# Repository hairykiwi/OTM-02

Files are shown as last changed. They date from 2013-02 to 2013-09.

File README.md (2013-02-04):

Open source Time Machine #2 - OTM-02
======

###About
OTM-02 is an open source watch module designed using [KiCad](http://www.kicad-pcb.org).
The project has a strong focus on using readily available off-the-shelf recent or latest technology, from global suppliers.

For the last few years I have eagerly awaited this period in time when really cool ultra-low power technology is readily available to the masses - so it's only right that a huge thanks goes out to Sharp Microelectronics for developing Memory LCD technology  - and an equally huge thanks goes to Energy Micro (EM) for not only supplying their ultra low power range of MCUs, but for having a level of customer support in place that even a relative novice like me feels they might just about be able to make something quite exciting. Within the Energy Micro team I would like to pay special thanks to Anders, Filip and Adam, without whose heavy-lifting work they've done with [code for Memory LCD](http://cdn.energymicro.com/dl/an/zip/an0048_efm32_energy_friendly_display.zip) technology, my current Memory LCD code would not be as efficiently integrated with EM's MCUs.

Right, enough waffle, you're here about a watch...

###Development
2013-02-02:
- [A functional development prototype does exists](http://dl.dropbox.com/u/18290329/hosted/OTM/OTM-01%20and%203D%20printed%20case%20concept_25pc.jpg). It uses a first generation Memory LCD model.
- No prototype has yet been manufactured - one is expected to be ready for showing by the end of Feb 2013.

A [discussion thread](http://forum.energymicro.com/topic/582-otm-02-open-source-time-machine-2/) has been posted at Energy Micro's [Lizard Lounge](http://forum.energymicro.com/) forum, where any questions, comments, critique, and suggestions for improvements are all welcome and appreciated.

###Objectives
- Create a watch module that enables the end user to have complete control of its functionality and user interface,
- Discover the benefits - and any detractions - of (potentially selling) a product developed from the outset in true open source hardware style,
- Self-education,
- Discover how much technology can be crammed into a wristwatch designed - and possibly manufactured - 'on the living room table',
- Design a module that with only a little extra effort, could form the basis of other devices, e.g. cycle computer, dive computer, data logger, etc.

###Features
The project utilises the following parts and features:
- [EFM32LG332F256](http://www.energymicro.com/products/efm32lg332f64-efm32lg332f128-efm32lg332f256) - A 32-bit, USB enabled, ultra low power Leopard Gecko ARM Cortex-M3 MCU from Energy Micro in Norway.
- [LS013B7DH03](http://www.sharpmemorylcd.com/1-28-inch-memory-lcd.html) - A 128 x 128 pixel ultra low power Memory LCD from Sharp Microelectronics,
- Recharge and programming via Micro USB connector,
- JTAG programming,
- 150mAh Li-Po Battery + on-board battery fuel gauge IC,
- Vibratory motor,
- Piezo Electric diaphragm,
- Five miniature right-angle tact switch buttons, (By MCU pin assignment and feature-set native to the EM MCU, with minor board layout editing, provision exists for alternate UI methods such as capacitive touch buttons.),
- Provision for a LED based planar light-guide type back light, (utilising a 0.4mm high right-angle Avago ChipLED and laser engraved light guide. (N.B. This is highly experimental and yet to be fully developed. Any derivatives of OTM-02 with commercial intent should be aware this technology is heavily patented.)
- Possible feature additions in modules developed subsequently include: accelerometer, Bluetooth LE, ANT+, GPS, memory expansion.

###Dimensions
- PCB size, (main area): 30.5 x 26.8 mm,
- PCB size, (including protruding Micro USB connector): 30.5 x 30.75 mm,
- LCD area: 30.3 x 26.6 mm  - 23.04 x 23.04 mm Active Area.

Total module thickness: 6.5 to 7mm including battery and piezoelectric diaphragm

###PCB details
Designed using KiCad version (2012-11-16 BZR 3805)-testing
**NOTE:** The files generated by this version are of the relatively new metric file format - I'm fairly certain the current stable release kicad-2012-01-19-BZR3256-stable WILL NOT READ the PCB files.
- One four layer board - total thickness: 1.0 mm,
- Minimum track width: 0.125 mm - as part of a controlled-impedance topology for USB data lines,
- Typical track width: 0.15 mm - 0.8 mm,
- Minimum via size: 0.55 mm x 0.3 mm drill.

###Cases
A non-waterproof, DIY 3D printing optimised case design is at an intermediate stage of development - see image link below.

Other cases, designed to be 3D printed in metal or other high-resolution materials are also in development.

The intention is to publish the source CAD data for at least one DIY 3D printable case design before the end of April 2013, earlier if possible.

###Images

http://bit.ly/mtmpublic

###Acknowledgements
A big thank you to the following people and organisations, without whose experience, guidance and encouragement, this would have taken much, much longer.
- Mark Burton at [SmartAvionics.com](http://www.smartavionics.com/)
- Chris Middlemiss, Paul Oliver - [Würth Elektronik - PCB division](http://we-online.com/web/en/leiterplatten/willkommen_/Willkommen.php)
- Anders, Filip and Adam - [Energy Micro](http://energymicro.com)
- Jorn Werdelin - [LindeWerdelin](http://lindewerdelin.com)
- [Olimex](http://olimex.com)
- [Sparkfun](http://sparkfun.com)
- [Review Display Systems](http://www.review-displays.co.uk/)
- [Avnet Embedded](http://www.avnet-embedded.eu/)
- + more acknowledments to come...

Special thanks goes especially to my wife - and family, friends and colleagues for putting up with my often ironic obsession with watch making - "It's nearly ready."

##Legal
**No warranty is expressed or implied.**

No content in this Github repo shall be considered as having been in anyway endorsed by any of the above mentioned companies or their representatives.

All intellectual property belonging to any third party mentioned remains respectively so.

###Licence
[CC-BY-SA 3.0](http://creativecommons.org/licenses/by-sa/3.0/)

*OTM-02* is [Open Source Hardware](http://www.oshwa.org/definition/) licensed under the Creative Commons Attribution-ShareAlike 3.0 Unported License and, excluding any proprietary files subject to third party copyright, will be open source firmware, likely released under the [GNU Lesser General Public License v3.0](http://www.gnu.org/copyleft/lesser.html)

**You are strongly encouraged to improve upon and hack OTM-02.**

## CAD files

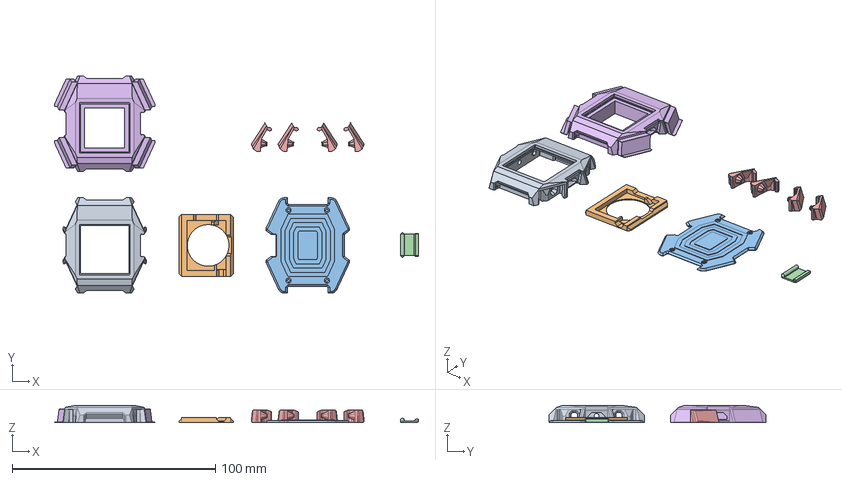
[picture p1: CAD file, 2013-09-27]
case/tinka/OTM-02-Case Tinka.stp
179.3 x 107.0 x 8.50 mm

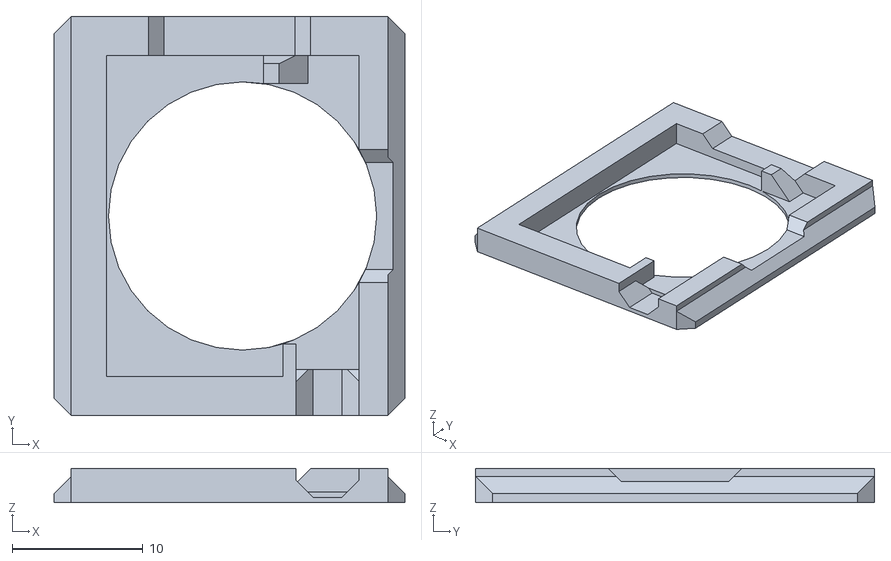
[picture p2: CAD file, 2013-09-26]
case/tinka/OTM-02 Case Tinka - Module Retainer (02-007-B1-v3).stl
26.8 x 30.5 x 2.60

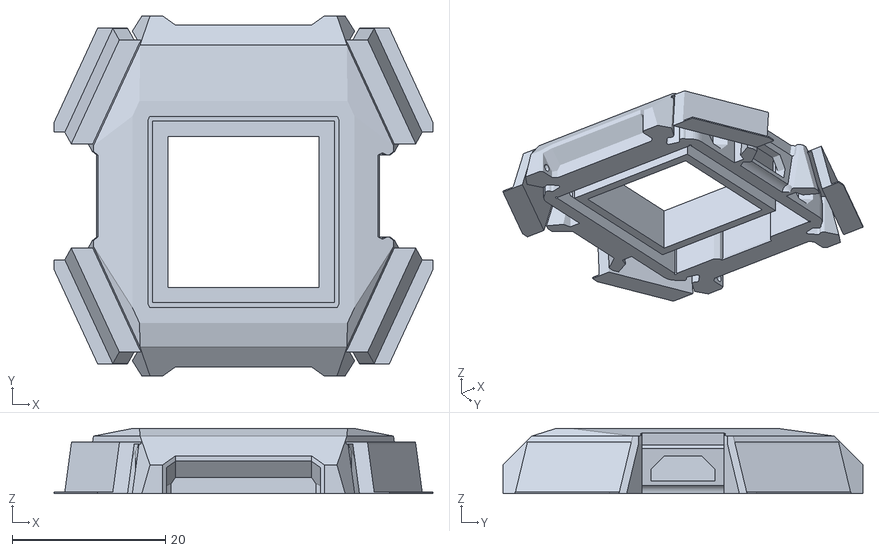
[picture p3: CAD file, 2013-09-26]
case/tinka/OTM-02 Case Tinka - Case Body, with support (02-007-B1-1-ws).stl
49.5 x 47.0 x 8.50

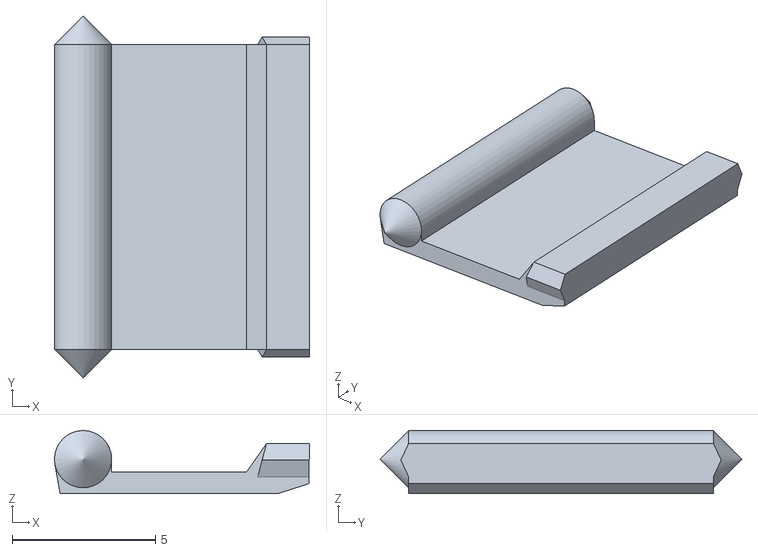
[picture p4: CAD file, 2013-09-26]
case/tinka/OTM-02 Case Tinka - USB Door (02-007-B1-Door-B).stl
8.91 x 12.6 x 2.20

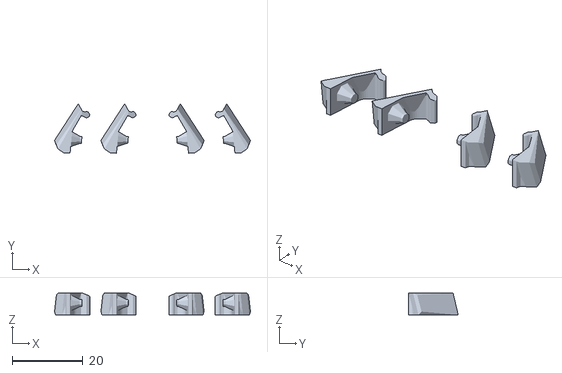
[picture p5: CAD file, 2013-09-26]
case/tinka/OTM-02 Case Tinka - Pushers (02-007-B1-N13-29-F2).stl
55.6 x 14.0 x 6.20

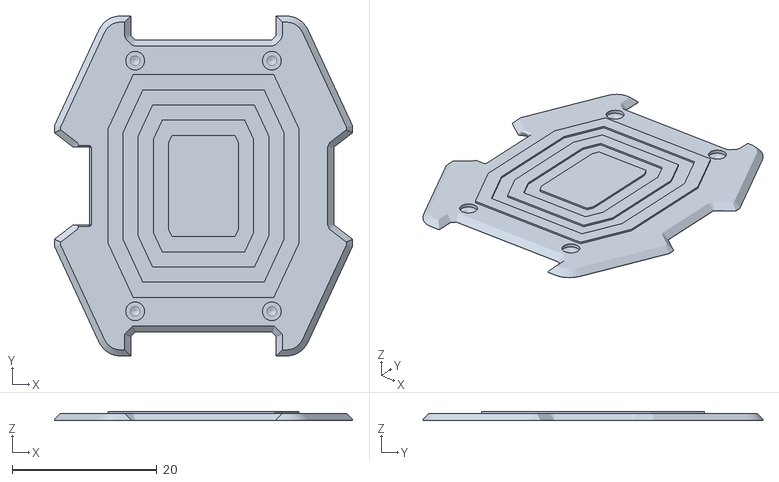
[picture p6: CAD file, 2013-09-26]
case/tinka/OTM-02 Case Tinka - Case Back (02-003-A-D-2-4).stl
41.2 x 47.0 x 1.25

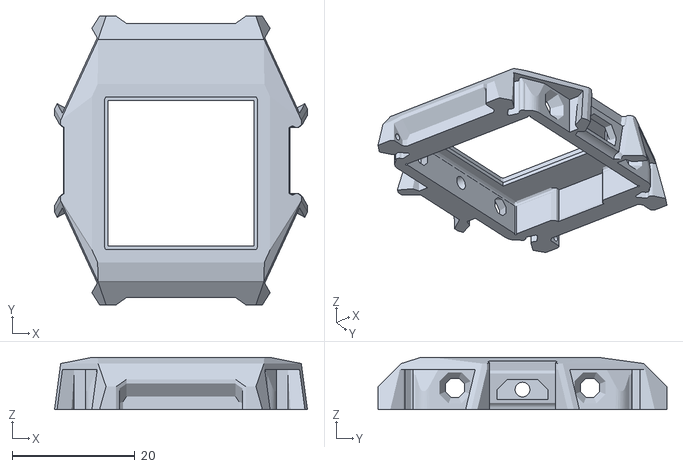
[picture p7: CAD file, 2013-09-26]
case/tinka/OTM-02 Case Tinka - Case Body (02-007-B1-1).stl
41.2 x 47.0 x 8.50

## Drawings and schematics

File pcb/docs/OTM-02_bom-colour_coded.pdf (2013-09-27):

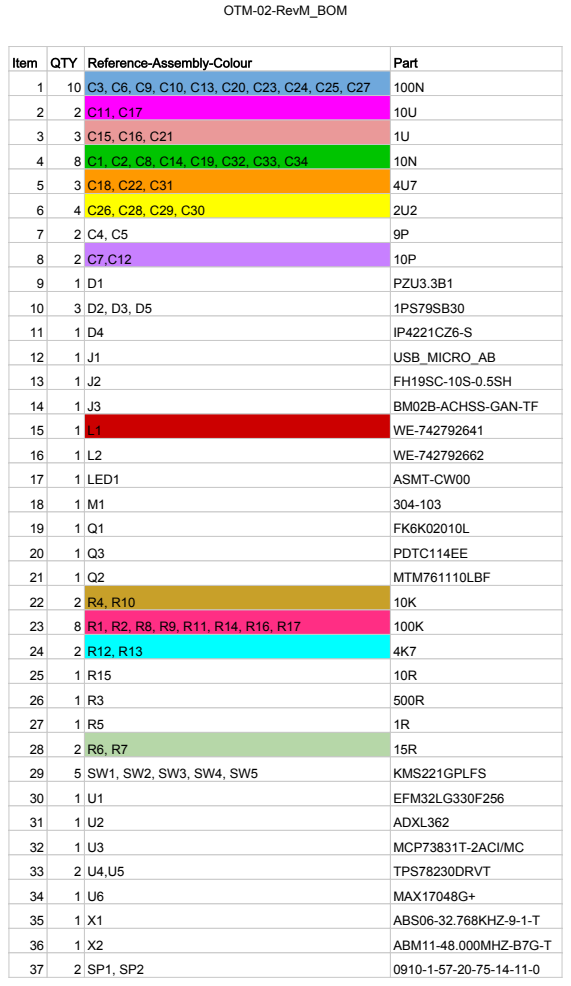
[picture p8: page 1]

Item | QTY | Reference-Assembly-Colour | Part

9 | 1 | D1 | PZU3.3B1

12 | 1 | J1 | USB_MICRO_AB

14 | 1 | J3 | BM02B-ACHSS-GAN-TF

17 | 1 | LED1 | ASMT-CW00

20 | 1 | Q3 | PDTC114EE

21 | 1 | Q2 | MTM761110LBF

29 | 5 | SW1, SW2, SW3, SW4, SW5 | KMS221GPLFS

30 | 1 | U1 | EFM32LG330F256

31 | 1 | U2 | ADXL362

32 | 1 | U3 | MCP73831T-2ACI/MC

33 | 2 | U4,U5 | TPS78230DRVT

34 | 1 | U6 | MAX17048G+

35 | 1 | X1 | ABS06-32.768KHZ-9-1-T

36 | 1 | X2 | ABM11-48.000MHZ-B7G-T

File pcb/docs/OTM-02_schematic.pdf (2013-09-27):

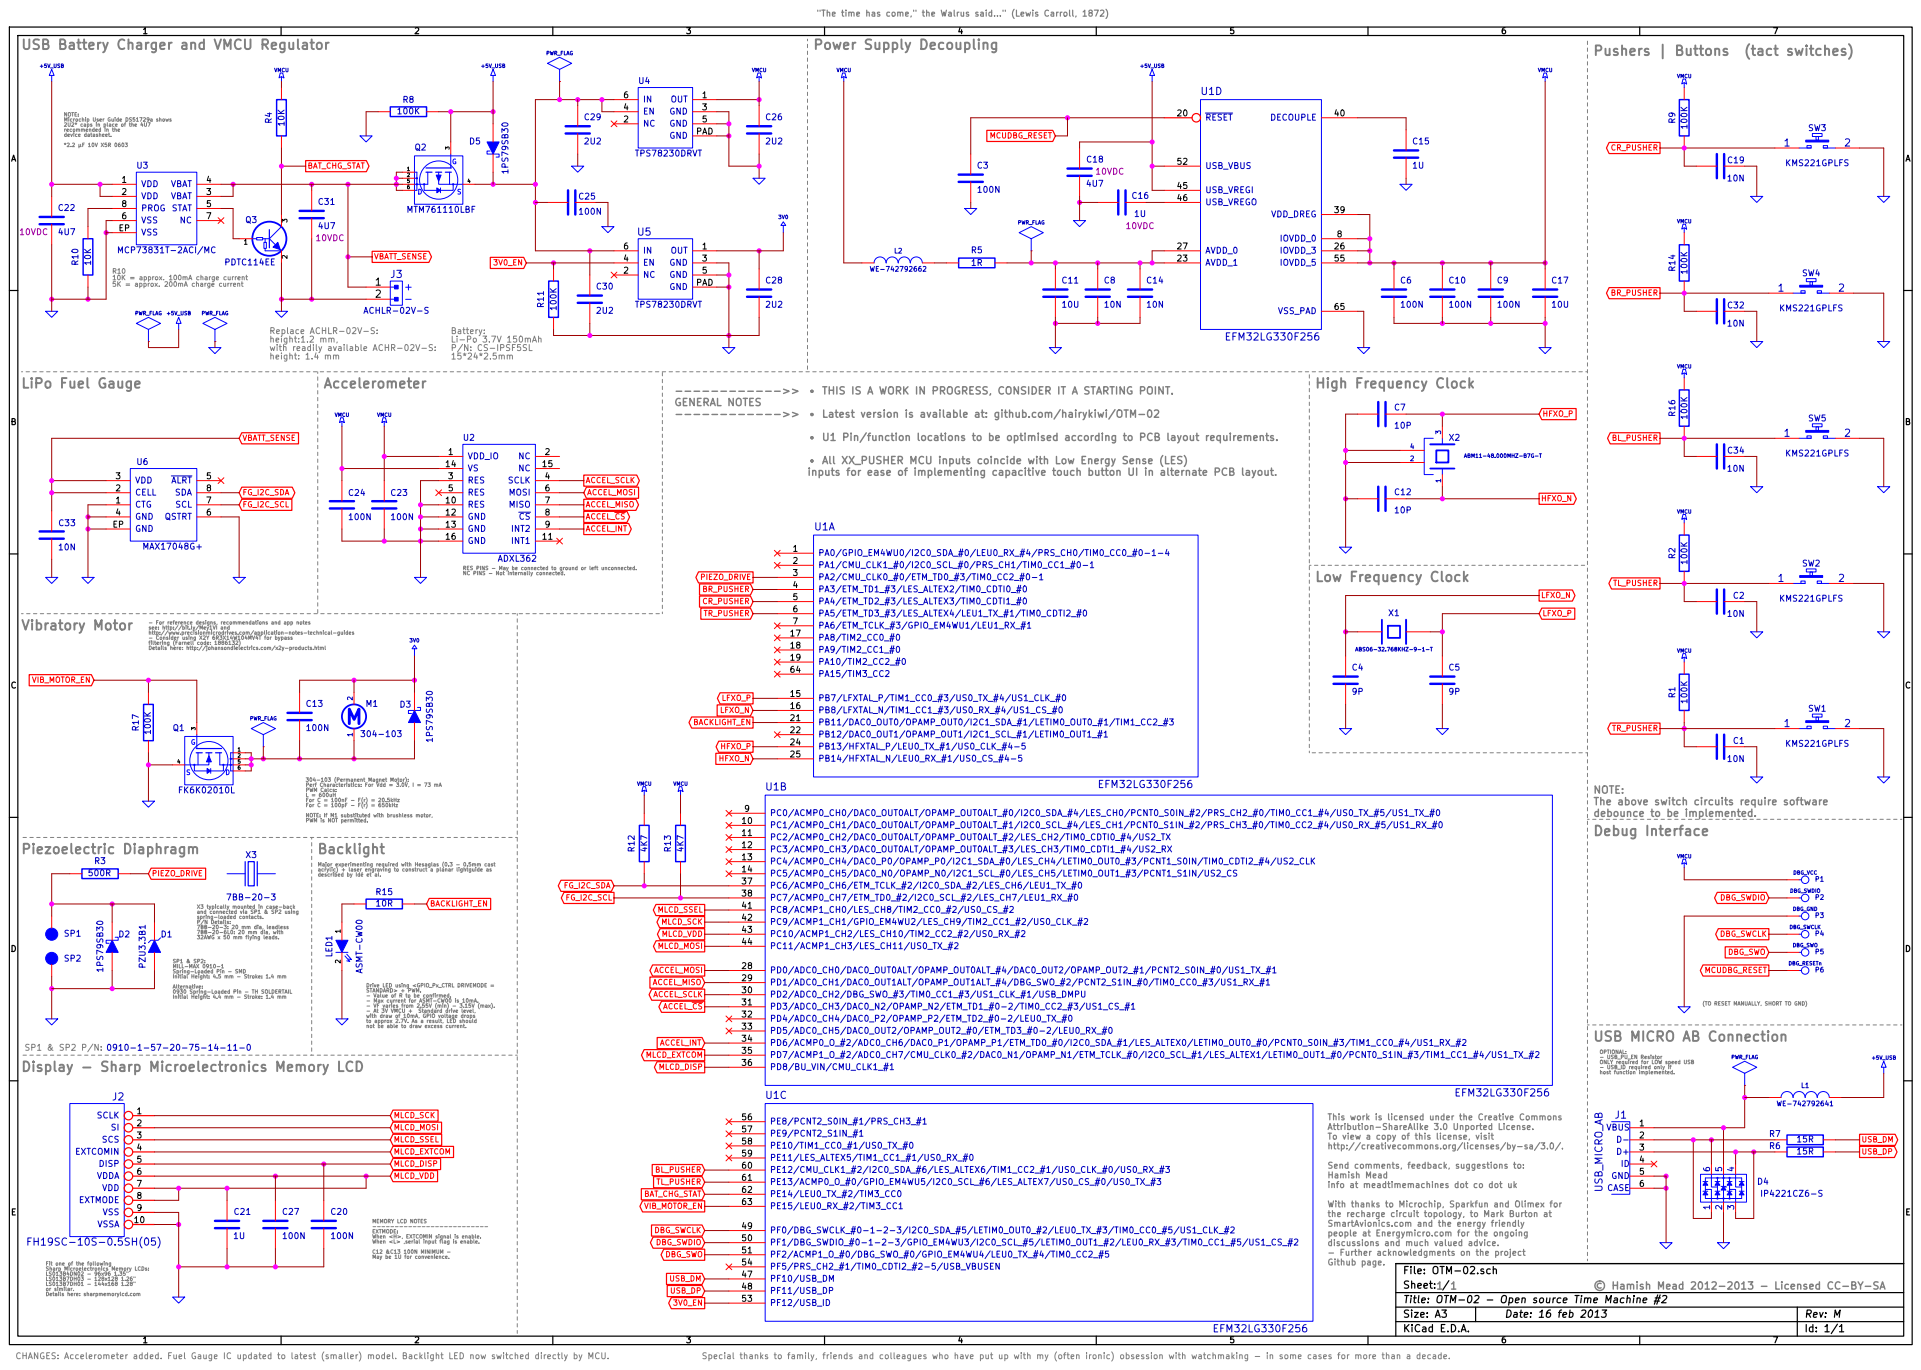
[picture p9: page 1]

"The time has come," the Walrus said..." (Lewis Carroll, 1872)
MCUDBG_RESET Power Supply Decoupling

U4 TPS78230DRVT USB Battery Charger and VMCU Regulator

NOTE: Microchip User Guide DS51729a shows 2U2* caps in place of the 4U7

10K = approx. 100mA charge current 5K = approx. 200mA charge current C22

1 2 LED1 ASMT-CW00 OUT 1 NC 2 GND 3 EN 4 GND 5

Replace ACHLR-02V-S: height:1.2 mm, with readily available ACHR-02V-S: height: 1.4 mm

Battery: Li-Po 3.7V 150mAh P/N: CS-IPSF5SL

THIS IS A WORK IN PROGRESS, CONSIDER IT A STARTING POINT.

Latest version is available at: github.com/hairykiwi/OTM-02

U1 Pin/function locations to be optimised according to PCB layout requirements.

DBG_VCC MLCD_SCK UEXT Connector (Olimex Standard)

All XX_PUSHER MCU inputs coincide with Low Energy Sense (LES)
inputs for ease of implementing capacitive touch button UI in alternate PCB layout.

- For reference designs, recommendations and app notes
see: http://bit.ly/Mey1VI and
http://www.precisionmicrodrives.com/application-notes-technical-guides
- Consider using X2Y 6R3X14W104MV4T for bypass

304-103 (Permanent Magnet Motor): Perf Characteristics: For Vdd = 3.0V, I = 73 mA
PWM Calcs: L = 600uH
For C = 100nF - F(r) = 20.5kHz For C = 100pF - F(r) = 650kHz NOTE: If M1 substituted with brushless motor, PWM is NOT permitted.

Initial Height: 4.4 mm - Stroke: 1.4 mm X3

to approx 2.7V. As a result, LED should not be able to draw excess current. R15

X3 typically mounted in case-back and connected via SP1 & SP2 using
spring-loaded contacts. P/N Details: 7BB-20-3: 20 mm dia, leadless 7BB-20-6L0: 20 mm dia, with

SP1 & SP2: MILL-MAX 0910-1 Spring-Loaded Pin - SMD

Initial Height: 4.5 mm - Stroke: 1.4 mm
Alternative: 0930 Spring-Loaded Pin - TH SOLDERTAIL

Drive LED using <GPIO_Px_CTRL DRIVEMODE = STANDARD> + PWM. - Value of R to be confirmed. - Max current for ASMT-CW00 is 10mA. - VF varies from 2.55V (min) - 3.15V (max). - At 3V VMCU + Standard drive level, with draw of 10mA, GPIO voltage drops

(TO RESET MANUALLY, SHORT TO GND) OPTIONAL: - USB_PU_EN Resistor ONLY required for LOW speed USB

- USB_ID required only if host function implemented.

L1 WE-742792641 MEMORY LCD NOTES

This work is licensed under the Creative Commons Attribution-ShareAlike 3.0 Unported License. To view a copy of this license, visit http://creativecommons.org/licenses/by-sa/3.0/. Send comments, feedback, suggestions to: Hamish Mead

info at meadtimemachines dot co dot uk With thanks to Microchip, Sparkfun and Olimex for

the recharge circuit topology, to Mark Burton at SmartAvionics.com and the energy friendly people at Energymicro.com for the ongoing

-------------------------- EXTMODE: When <H>, EXTCOMIN signal is enable. When <L> ,serial input flag is enable. C12 &C13 100N MINIMUM - May be 1U for convenience.

Id: 1/1 Title: OTM-02 - Open source Time Machine #2 File: OTM-02.sch Sheet: / Fit one of the following Sharp Microelectronics Memory LCDs: LS013B4DN02 - 96x96 1.35" LS013B7DH03 - 128x128 1.26" LS013B7DH01 - 144x168 1.28" or similar. Details here: sharpmemorylcd.com

Special thanks to family, friends and colleagues who have put up with my (often ironic) obsession with watchmaking - in some cases for more than a decade.

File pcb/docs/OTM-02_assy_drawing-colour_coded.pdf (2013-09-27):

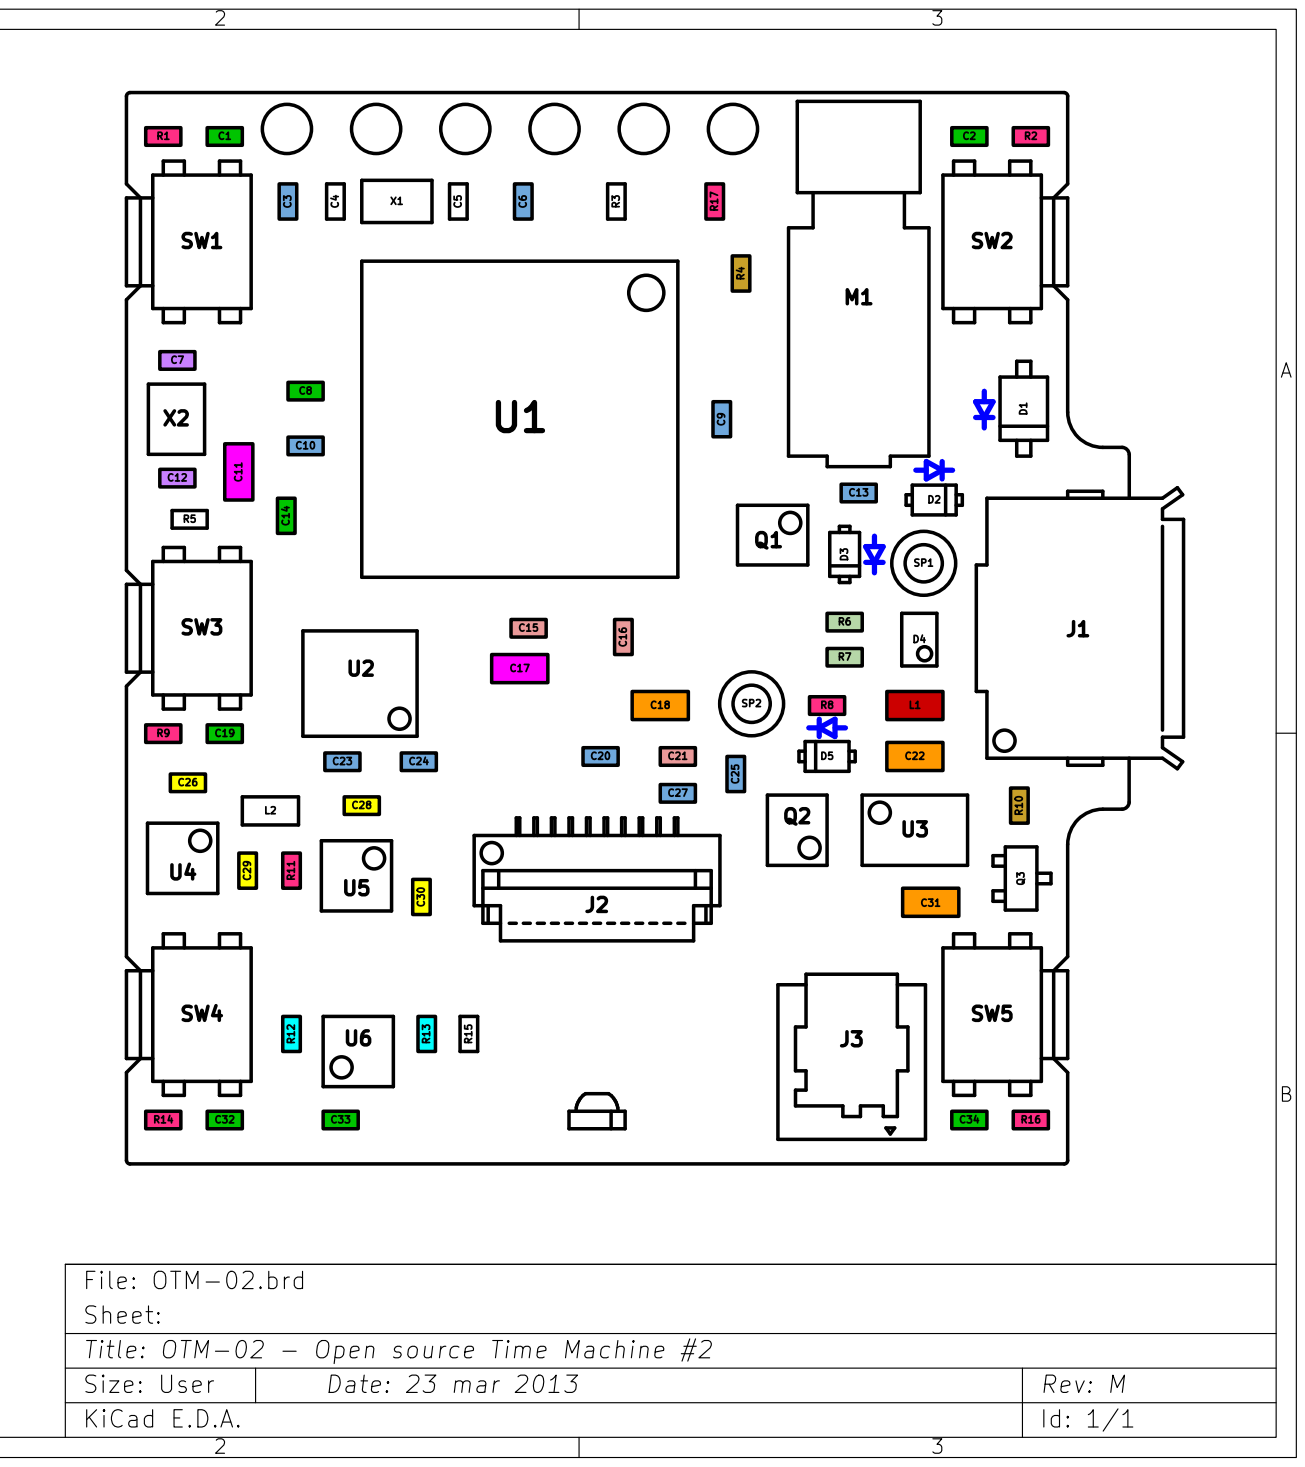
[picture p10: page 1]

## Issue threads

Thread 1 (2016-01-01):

Any hopes to resurrect the project? MetaWatch isn't so Open and featured, Pebble is closed, TI Chronos too

timofonic, 2016-01-01:
Hello.

Any hopes to resurrect the project? I would love to use it for me personal device (a portable server + portable lab + soldering station + battery pack), it's going to have a very iterative development process.

Kind regards.

hairykiwi, 2016-01-01:
Hello - Yes! Please do use it for anything. It never really died, I just needed time out from working on it as intensely as I was - then I got distracted with everything else I dabble in. The prototype still works well enough for daily use on my wrist, but no where near as accurate or power efficient as it could be.

The question is where to begin the resurrection. Here's an overview of some of the bigger issues - all interdependent to one extent or other:

- PCB needs migrating to the latest KiCad file formats, (solder mask needs editing for less solder per pad),
- vibe motor power switch MOSFET is superfluous, (getting rid of it could enable fitting a pressure sensor)
- LED backlight needs developing (I have some 0.4mm thick acrylic sheet, 0.4mm thick side-firing LEDs and an idea to test for generating a diffuser pattern using a cheap laser engraver - just need to find time)
- MCU brand/features need reassessing: The EFM32 with hardware AES encryption running opensource firmware seems to be a PITA to ship to end customers in as much as there's some serious  (USA && UK Dept for Trade) record-keeping obligations. As a result I'd be very tempted to re-spin the PCB for a STM part without AES. Many (all?) STM MCUs have a nice hardware solution for 'on the fly' RTC timing corrections which interests me more than AES, but I understand hardware AES may be more useful in many applications.

Thanks for your interest. BTW, 'very iterative' is good - we may have at least something in common there.

Cheers :)

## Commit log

2013-02-02 gitignore created
    KiCad project .gitignore - to be tweaked.
2013-02-03 PCB initial commit - Rev.L
    Minor changes from initial (Dropbox) release:
    - .gitignore added (may need tweaking),
    - .pro file now contains relative references to lib directory and files,
    - schematic and PCB drawing boarders now utilise proper fields,
    - assy_drawing.pdf added (however component idents unreadable - FIXME),
    - reference to revsion in file names removed.
    [$OTM-02.brd, OTM-02.brd, OTM-02.sch]
2013-02-03 deletion of duplicate .brd file
    [$OTM-02.brd]
2013-02-04 added KiCad version info, more credits and typo correction
2013-06-12 Rev.M - Accelerometer (ADXL362) added to PCB
    This commit reflects the OTM-02-Rev.M PCB's as manufactured in Feb 2013.
    Some GPIO rerouting was required to add the ADXL362.
    As of commit date, the Memory LCD display, USB recharge circuit, five (5)
    switches and vibratory motor all appear to be functioning as intended. The LED
    GPIO also functions, however no LED has yet been connected. PWM on the
    LED GPIO *may* require implementing to prevent damage to the LED and/or
    GPIO.
    The following circuits (i.e. software communication) are yet to be tested:
    Accelerometer, Li-Po fuel gauge.
    [OTM-02.brd, OTM-02.sch]
2013-06-23 Retrospective commit message correction + housekeeping + minor updates.
    The previous commit message omitted some of the major changes
    between Rev.L and Rev.M.
    The major changes as of the previous commit (initial commit of rev.M) were:
    - Accelerometer added (ADXL362).
    - Battery 'Fuel Gauge' IC (MAX17043G+U) updated to smaller (MAX17048G+).
    - Backlight LED switched directly by EFM32, (i.e. MOSFET switch removed).
    Changes introduced as of *this* commit:
    - Debug Interface 'P7' relabelled 'P6', to reflect actual total pin count.
    - Piezoelectric diaphragm (PED) connections (pads) labelled 'PADx',
    relabelled 'SPx' to better reflect the Spring Pin component fitted.
    - PED SP module (PCB footprint)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
    [OTM-02.brd, OTM-02.sch]
2013-09-26 Tinka - A DIY 3D printable watch case for OTM-02
    - Finally, a fully functional 3D printed watch case for OTM-02!
    - As seen on the RepRap Community Hub (stand G54) at the TCT Show,
    25-26 September 2013, NEC, Birminham, UK.
    - Designed using MoI3D.
    - The design has been sucessfully printed in PLA on a
    Prusa Mendel using a 0.5 mm dia nozzle, single shell thickness,
    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
    [OTM-02 Case Tinka - Case Back (02-003-A-D-2-4).stl, OTM-02 Case Tinka - Case Body (02-007-B1-1).stl, OTM-02 Case Tinka - Case Body, with support (02-007-B1-1-w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]
2013-09-27 Late-night-spelling-gremlin erradication.
    [OTM-02 Case Tinka - Pushers (02-007-B1-N13-29-F2).stl, OTM-02-Case Tinka.stp]
